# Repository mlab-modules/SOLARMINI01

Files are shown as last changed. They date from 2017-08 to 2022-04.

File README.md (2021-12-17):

[Czech](./README.cs.md)
<!--- module --->
# SOLARMINI01A
<!--- Emodule --->

<!--- subtitle ---> MPPT module for up to 5 Watt photovoltaic panel.<!--- Esubtitle --->

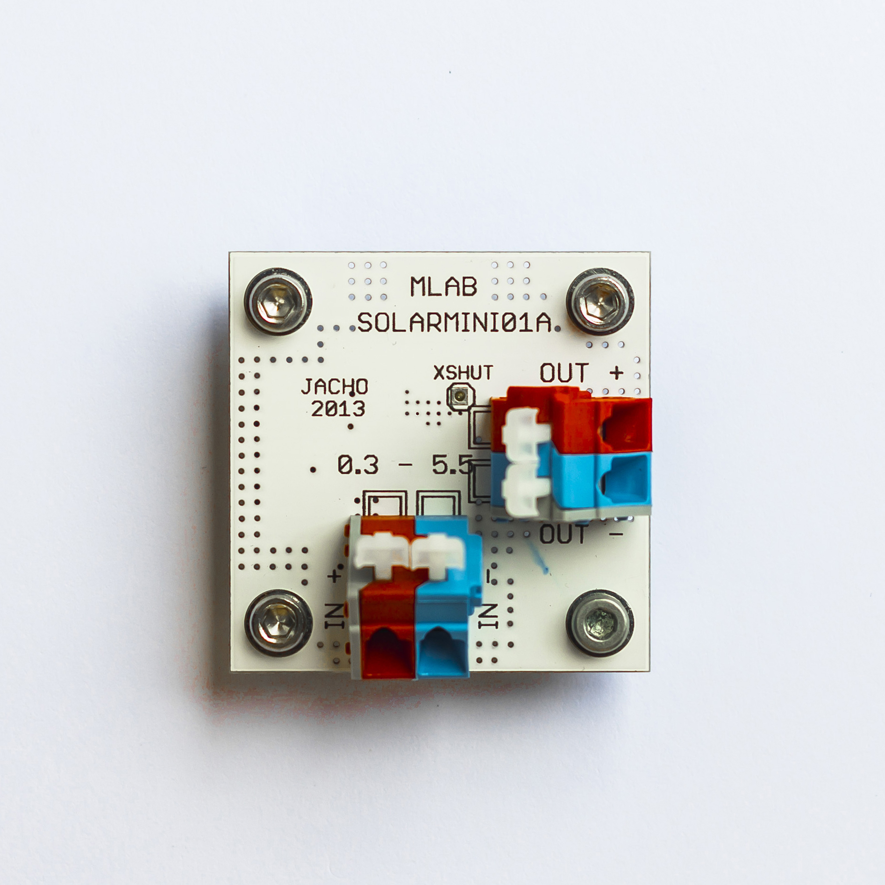
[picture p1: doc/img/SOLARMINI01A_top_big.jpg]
SOLARMINI01A


<!--- description ---> Module permanently search maximum power point of connected photovoltaic panel and convert the generated energy to higher voltages (5V maximum). It can be used for single cell or few serial connected cells. <!--- Edescription --->

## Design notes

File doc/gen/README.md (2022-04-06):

# PCB

Board size: 40.13x40.13 mm (1.58x1.58 inches)

- This is the size of the rectangle that contains the board
- Thickness: 1.6 mm (63 mils)
- Material: FR4
- Finish: None
- Layers: 2
- Copper thickness: 35 µm

Solder mask: TOP / BOTTOM

- Color: Green

Silk screen: TOP / BOTTOM

- Color: White

Stackup:

| Name | Type | Color | Thickness | Material | Epsilon_r | Loss tangent |
|---|---|---|---|---|---|---|
| F.SilkS | Top Silk Screen | | | | | |
| F.Paste | Top Solder Paste | | | | | |
| F.Mask | Top Solder Mask | Green | 10 | | | |
| F.Cu | copper | | 35 | | | |
| dielectric 1 | core | | 1510 | FR4 | 4.5 | 0.02 |
| B.Cu | copper | | 35 | | | |
| B.Mask | Bottom Solder Mask | Green | 10 | | | |
| B.Paste | Bottom Solder Paste  | | | | | |
| B.SilkS | Bottom Silk Screen | | | | | |

# Important sizes

Clearance: 0.2 mm (8 mils)

Track width: 0.3 mm (12 mils)

- By design rules: 0.2 mm (8 mils)

Drill: 0.4 mm (16 mils)

- Vias: 0.4 mm (16 mils) [Design: 0.3 mm (12 mils)]
- Pads: 0.89 mm (35 mils)

Via: 0.8/0.4 mm (31/16 mils)

- By design rules: 0.4/0.3 mm (16/12 mils)
- Micro via: no [0.2/0.1 mm (8/4 mils)]
- Burried/blind via: no

Outer Annular Ring: 0.4 mm (16 mils)

- By design rules: 0.4 mm (16 mils)

Eurocircuits class: 4C

# General stats

Components count: (SMD/THT)

- Top: 0/8 (THT)
- Bottom: 19/1 (SMD + THT)

Defined tracks:

- 0.2 mm (8 mils)
- 0.3 mm (12 mils)
- 0.4 mm (16 mils)
- 0.5 mm (20 mils)
- 0.6 mm (24 mils)
- 0.7 mm (28 mils)
- 1.0 mm (39 mils)

Used tracks:

- 0.3 mm (12 mils) (18) defined: yes
- 0.5 mm (20 mils) (29) defined: yes

Defined vias:

- 0.8/0.4 mm (31/16 mils)

Used vias:

- 0.8/0.4 mm (31/16 mils) (Count: 67, Aspect: 2.0 A) defined: yes

Holes (excluding vias):

- 0.89 mm (35 mils) (7)
- 1.3 mm (51 mils) (4)
- 3.0 mm (118 mils) (4)

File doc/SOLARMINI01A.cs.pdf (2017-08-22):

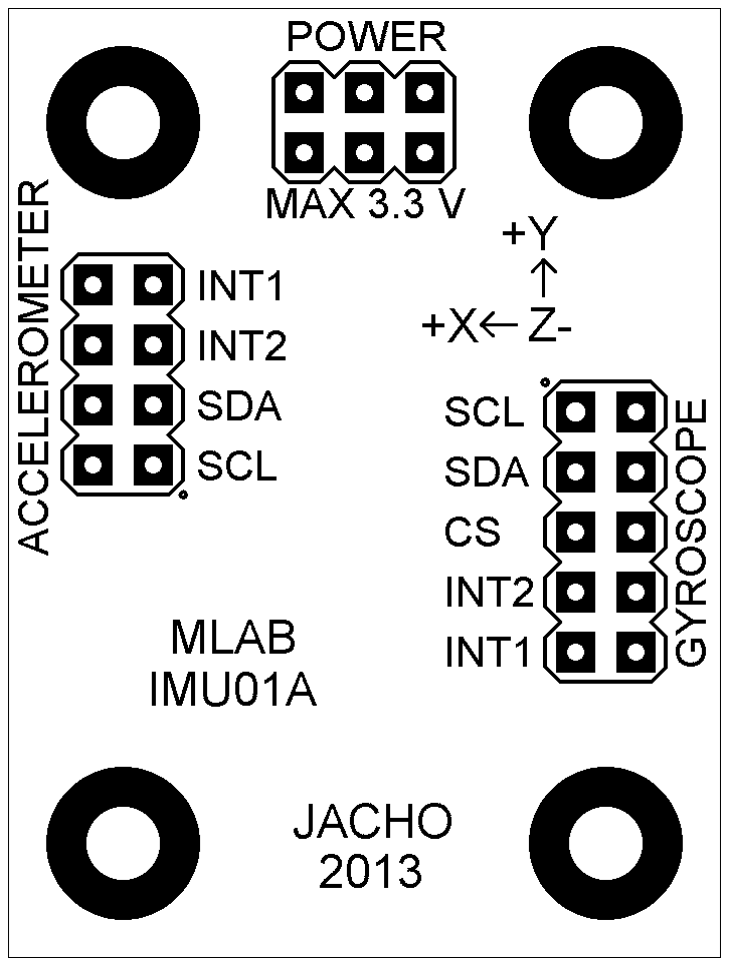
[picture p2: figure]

SOLARMINI01A / 2016-03-09 / jacho / http://www.mlab.cz | 1 / 3
SOLARMINI01A | MLAB

# DC/DC měnič pro solární články

Jan Chroust

# 1. Technické parametry

Parametr | Hodnota | Poznámka

Napájení

Integrovaný obvod

Využití

Rozhraní

Rozměry | 40.13 x 40.13 x 16 mm | Výška nad základní deskou

SOLARMINI01A | MLAB

# 2. Popis konstrukce

## 2.1. Úvod

## 2.2. Zapojení

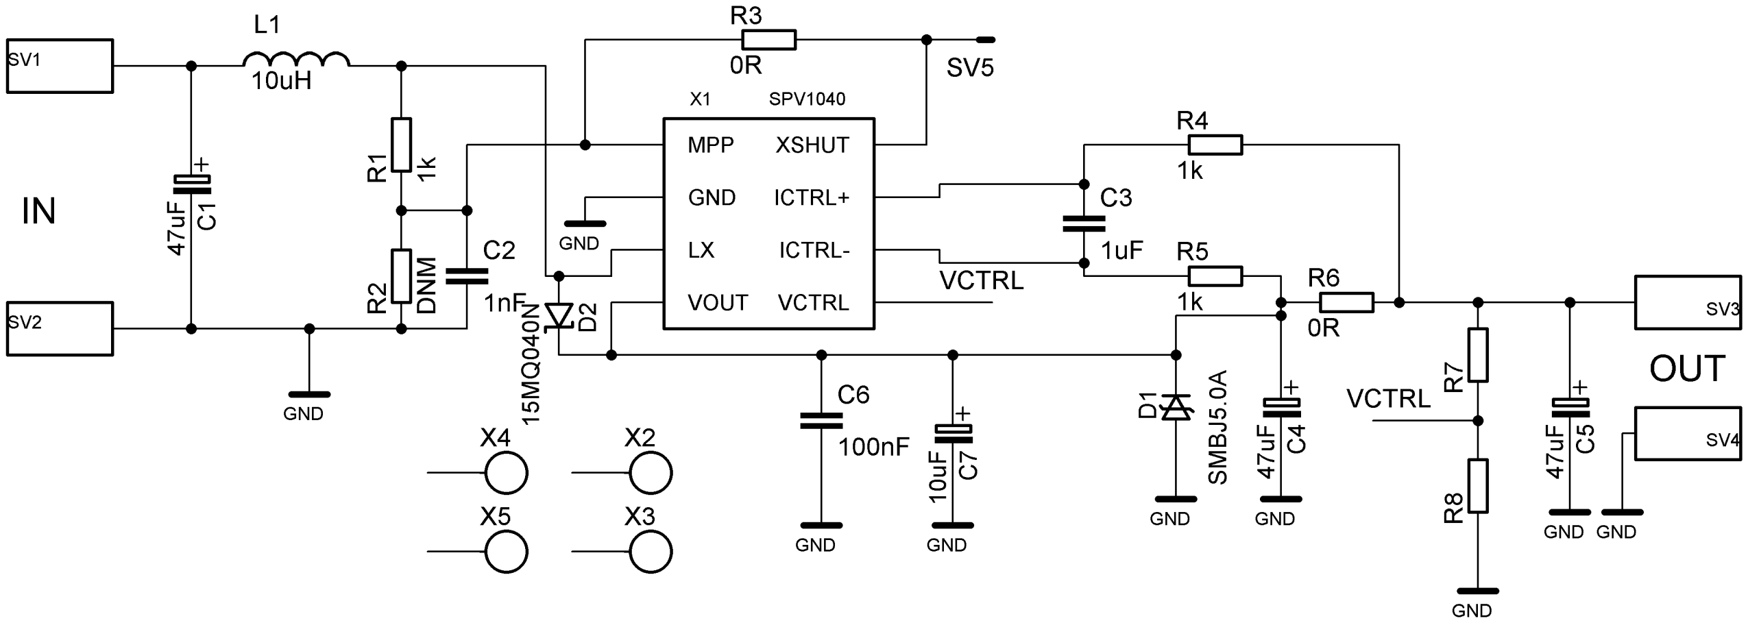
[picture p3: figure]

# 3. Osazení a oživení

SOLARMINI01A | MLAB

## 3.1. Osazení

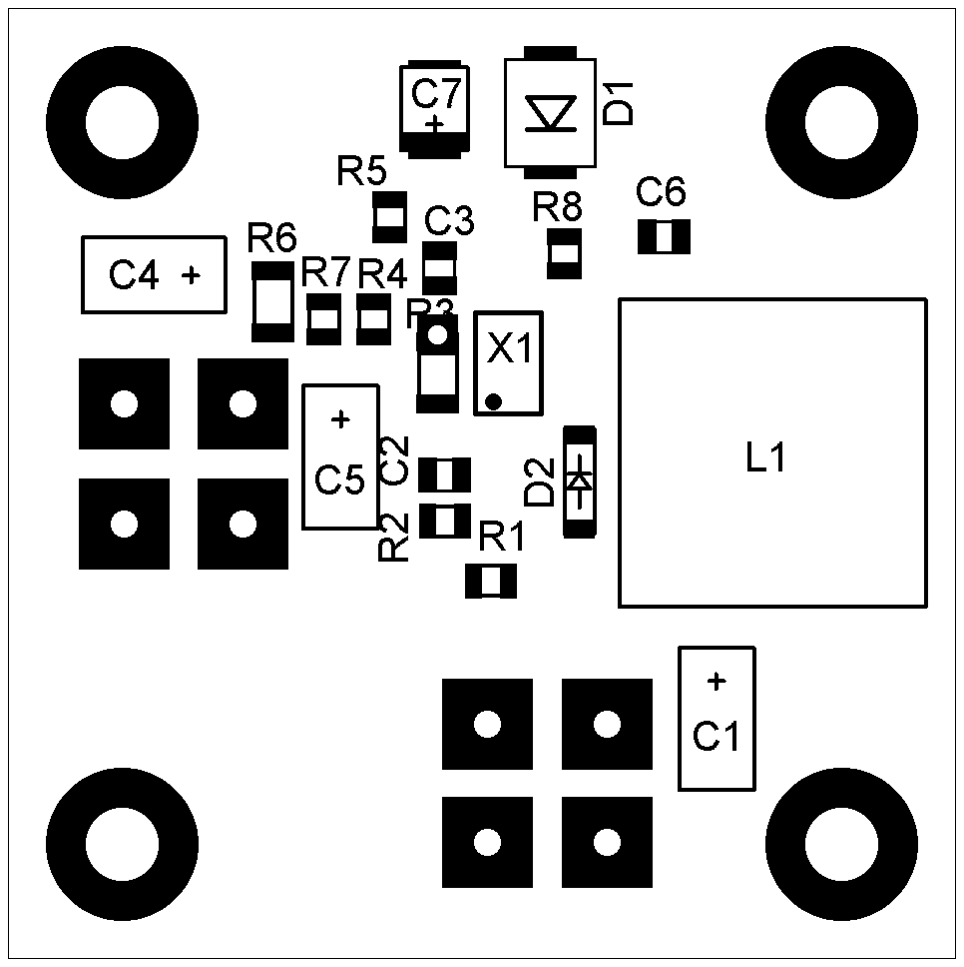
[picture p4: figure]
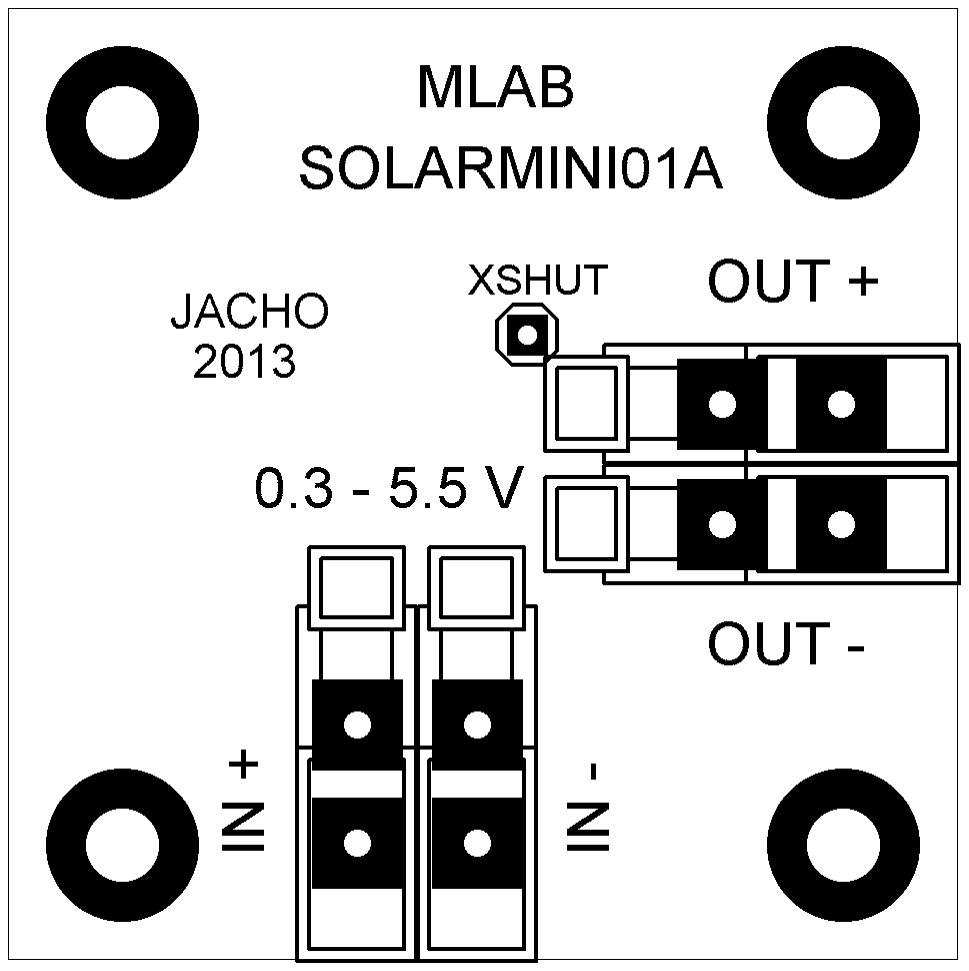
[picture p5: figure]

Označení | Typ (pouzdro) | Označení | Typ (pouzdro)
C1,C4, C5 | 47uF ( C ) | R1, R4, R5 | 1k (0805)
C2 | 1nF (0805) | R2 | DNM (0805)
C3 | 1uF (0805) | R3, R6 | 0R (1206)
C6 | 100nF (0805) | R7 | X (0805)
C7 | 10uF (B) | R8 | X(0805)
D1 | SMBJ5.0A (SMA) | SV1 - SV4 | WAGO256
D2 | 15MQ040N (SMA) | X1 | SPV1040
L1 | DE1205-10 | X2 - X5 | Šroub M3

## 3.2. Oživení

Po osazení modulu je dobré provést vizuální kontrolu, případně proměřit, zda na napájení není zkrat. Další oživení není potřeba.

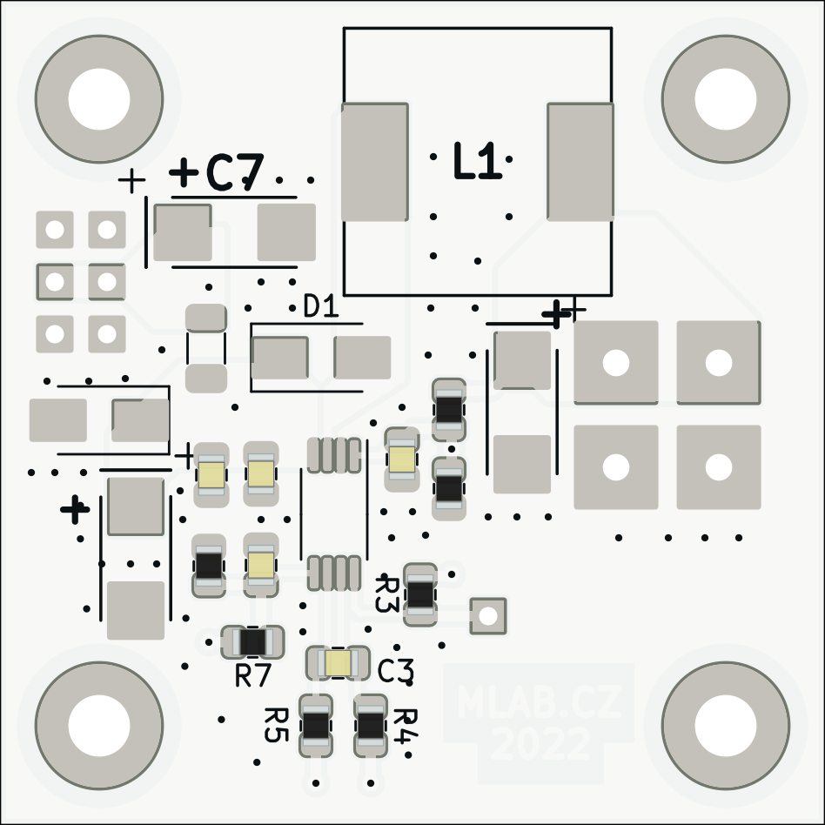
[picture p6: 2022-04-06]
doc/gen/img/SOLARMINI01B-bottom.png

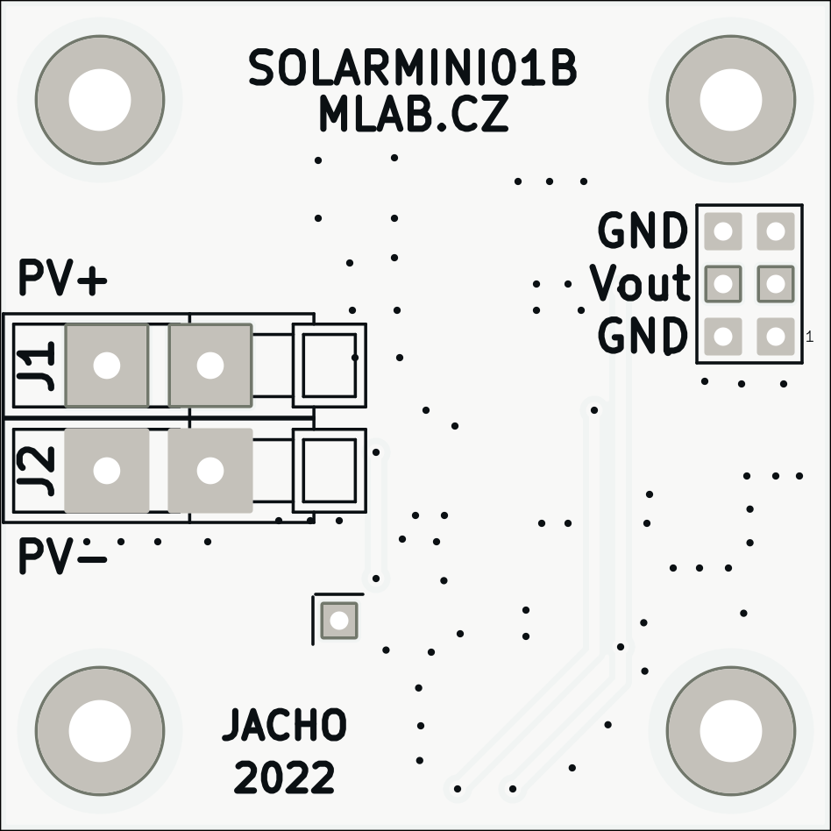
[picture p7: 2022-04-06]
doc/gen/img/SOLARMINI01B-top.png

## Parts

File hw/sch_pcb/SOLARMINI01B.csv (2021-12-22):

Source: | F:\MLAB_G\Moduly_zvlast\SOLARMINI01\hw\sch_pcb\SOLARMINI01B.kicad_sch
Date: | 22.12.2021 12:41:42
Tool: | Eeschema (5.99.0-13046-g4fe9f01eb0)
Generator: | C:\Program Files\KiCad\5.99\bin\scripting\plugins/bom_csv_grouped_by_value.py
Component Count: | 28
Individual Components:
Item | Qty | Reference(s) | Value | LibPart | Footprint | Datasheet | UST_ID
 |  | C1 | 47uF/16 | Device:C_Polarized | Mlab_C:TantalC_SizeC_Reflow | ~ | 5c70984412875079b91f8867
 |  | C2 | 100nF | Device:C | Capacitor_SMD:C_0805_2012Metric | ~ | 5c70984712875079b91f8b4c
 |  | C3 | 1uF | Device:C | Capacitor_SMD:C_0805_2012Metric | ~ | 5c70984712875079b91f8b50
 |  | C4 | 100nF | Device:C | Capacitor_SMD:C_0805_2012Metric | ~ | 5c70984712875079b91f8b4c
 |  | C5 | 10uF | Device:C | Capacitor_SMD:C_0805_2012Metric | ~ | 5c70984812875079b91f8bbd
 |  | C6 | 47uF/16 | Device:C_Polarized | Mlab_C:TantalC_SizeC_Reflow | ~ | 5c70984412875079b91f8867
 |  | C7 | 47uF/16 | Device:C_Polarized | Mlab_C:TantalC_SizeC_Reflow | ~ | 5c70984412875079b91f8867
 |  | C8 | 1nF | Device:C | Capacitor_SMD:C_0805_2012Metric | ~ | 5c70984712875079b91f8b45
 |  | D1 | 15MQ040N | Device:D_Schottky | Diode_SMD:D_SMA | ~ | 5c70984512875079b91f88b0
 |  | D2 | SMBJ5.0A | Device:D_Zener | Diode_SMD:D_SMA | ~ | 5c70984512875079b91f88c7
 |  | J1 | WAGO 256 RED | MLAB_Jumpers:CONN1_1 | Mlab_CON:WAGO256 |  | 5c70984412875079b91f87c5
 |  | J2 | WAGO 256 BLUE | MLAB_Jumpers:CONN1_1 | Mlab_CON:WAGO256 |  | 5c70984412875079b91f87c3
 |  | J3 | HEADER_1x01 | MLAB_HEADER:HEADER_1x01 | Mlab_Pin_Headers:Straight_1x01
 |  | J4 | HEADER_2x03_PARALLEL | MLAB_HEADER:HEADER_2x03_PARALLEL | Mlab_Pin_Headers:Straight_2x03
 |  | L1 | 10uH - DE1205-10 | Device:L_Small | Mlab_L:DE1205-10 | ~ | 5c70984412875079b91f8822
 |  | M1 | HOLE | MLAB_MECHANICAL:HOLE | Mlab_Mechanical:MountingHole_3mm
 |  | M2 | HOLE | MLAB_MECHANICAL:HOLE | Mlab_Mechanical:MountingHole_3mm
 |  | M3 | HOLE | MLAB_MECHANICAL:HOLE | Mlab_Mechanical:MountingHole_3mm
 |  | M4 | HOLE | MLAB_MECHANICAL:HOLE | Mlab_Mechanical:MountingHole_3mm
 |  | R1 | 1k | Device:R | Resistor_SMD:R_0805_2012Metric | ~ | 5c70984512875079b91f898c
 |  | R2 | - | Device:R | Resistor_SMD:R_0805_2012Metric | ~
 |  | R3 | 0R | Device:R | Resistor_SMD:R_0805_2012Metric | ~ | 5c70984512875079b91f896b
 |  | R4 | 1k | Device:R | Resistor_SMD:R_0805_2012Metric | ~ | 5c70984512875079b91f898c
 |  | R5 | 1k | Device:R | Resistor_SMD:R_0805_2012Metric | ~ | 5c70984512875079b91f898c
 |  | R6 | 0R47 | Device:R | Resistor_SMD:R_1206_3216Metric | ~ | 60be2ed51287500165e6c1cd
 |  | R7 | 560k | Device:R | Resistor_SMD:R_0805_2012Metric | ~ | 5c70984712875079b91f8aa6
 |  | R8 | 270k | Device:R | Resistor_SMD:R_0805_2012Metric | ~ | 5c70984712875079b91f8aa0
 |  | U1 | SPV1040 | MLAB_IO:SPV1040 | Package_SO:TSSOP-8_4.4x3mm_P0.65mm |  | 5c70984612875079b91f89bc
Collated Components:
Item | Qty | Reference(s) | Value | LibPart | Footprint | Datasheet | UST_ID
1 | 3 | C1, C6, C7 | 47uF/16 | Device:C_Polarized | Mlab_C:TantalC_SizeC_Reflow | ~ | 5c70984412875079b91f8867
2 | 2 | C2, C4 | 100nF | Device:C | Capacitor_SMD:C_0805_2012Metric | ~ | 5c70984712875079b91f8b4c
3 | 1 | C3 | 1uF | Device:C | Capacitor_SMD:C_0805_2012Metric | ~ | 5c70984712875079b91f8b50
4 | 1 | C5 | 10uF | Device:C | Capacitor_SMD:C_0805_2012Metric | ~ | 5c70984812875079b91f8bbd
5 | 1 | C8 | 1nF | Device:C | Capacitor_SMD:C_0805_2012Metric | ~ | 5c70984712875079b91f8b45
6 | 1 | D1 | 15MQ040N | Device:D_Schottky | Diode_SMD:D_SMA | ~ | 5c70984512875079b91f88b0
7 | 1 | D2 | SMBJ5.0A | Device:D_Zener | Diode_SMD:D_SMA | ~ | 5c70984512875079b91f88c7
8 | 1 | J1 | WAGO 256 RED | MLAB_Jumpers:CONN1_1 | Mlab_CON:WAGO256 |  | 5c70984412875079b91f87c5
9 | 1 | J2 | WAGO 256 BLUE | MLAB_Jumpers:CONN1_1 | Mlab_CON:WAGO256 |  | 5c70984412875079b91f87c3
10 | 1 | J3 | HEADER_1x01 | MLAB_HEADER:HEADER_1x01 | Mlab_Pin_Headers:Straight_1x01
11 | 1 | J4 | HEADER_2x03_PARALLEL | MLAB_HEADER:HEADER_2x03_PARALLEL | Mlab_Pin_Headers:Straight_2x03
12 | 1 | L1 | 10uH - DE1205-10 | Device:L_Small | Mlab_L:DE1205-10 | ~ | 5c70984412875079b91f8822
13 | 4 | M1, M2, M3, M4 | HOLE | MLAB_MECHANICAL:HOLE | Mlab_Mechanical:MountingHole_3mm
14 | 3 | R1, R4, R5 | 1k | Device:R | Resistor_SMD:R_0805_2012Metric | ~ | 5c70984512875079b91f898c
15 | 1 | R2 | - | Device:R | Resistor_SMD:R_0805_2012Metric | ~
16 | 1 | R3 | 0R | Device:R | Resistor_SMD:R_0805_2012Metric | ~ | 5c70984512875079b91f896b
17 | 1 | R6 | 0R47 | Device:R | Resistor_SMD:R_1206_3216Metric | ~ | 60be2ed51287500165e6c1cd
18 | 1 | R7 | 560k | Device:R | Resistor_SMD:R_0805_2012Metric | ~ | 5c70984712875079b91f8aa6
19 | 1 | R8 | 270k | Device:R | Resistor_SMD:R_0805_2012Metric | ~ | 5c70984712875079b91f8aa0
20 | 1 | U1 | SPV1040 | MLAB_IO:SPV1040 | Package_SO:TSSOP-8_4.4x3mm_P0.65mm |  | 5c70984612875079b91f89bc

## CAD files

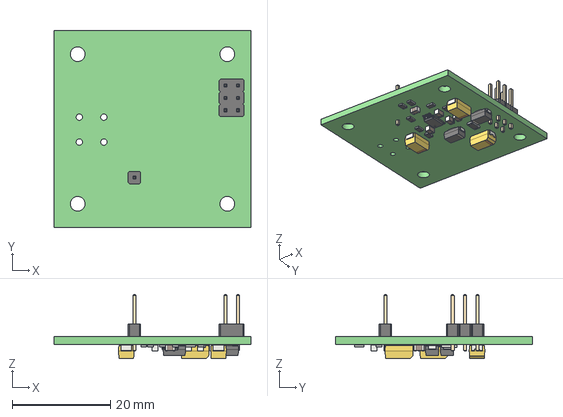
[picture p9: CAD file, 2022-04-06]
doc/gen/SOLARMINI01B.step
40.1 x 40.1 x 13.0 mm
tmp5e7hpwy7 PCB

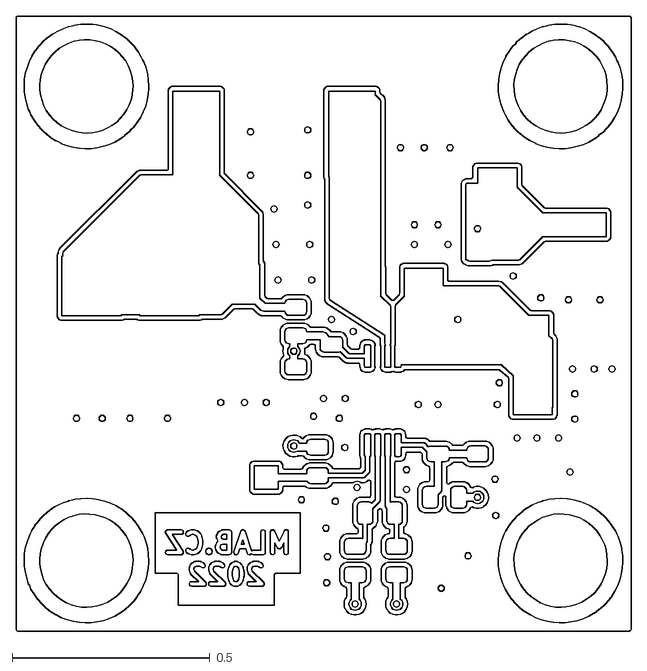
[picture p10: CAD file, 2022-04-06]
doc/gen/dxf/SOLARMINI01B-B_Cu.dxf
1.56 x 1.56

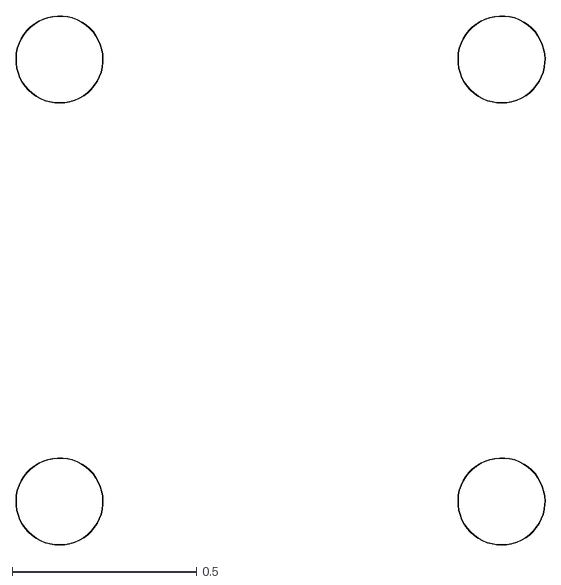
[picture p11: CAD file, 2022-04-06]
doc/gen/dxf/SOLARMINI01B-B_Adhesive.dxf
1.44 x 1.44

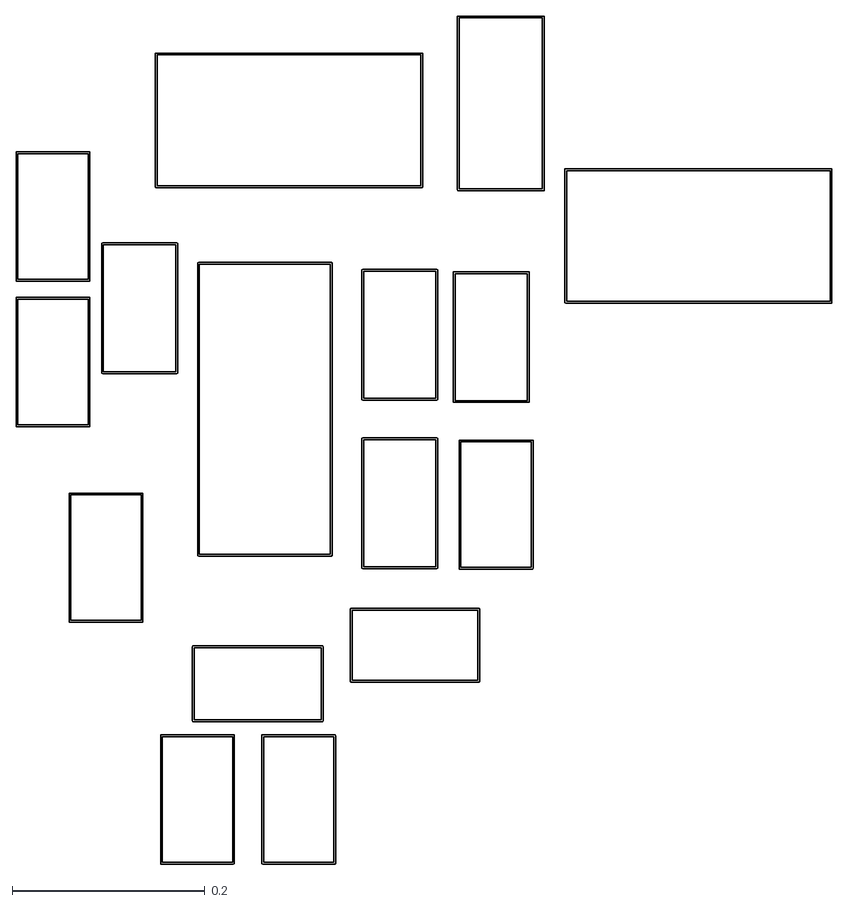
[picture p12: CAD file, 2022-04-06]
doc/gen/dxf/SOLARMINI01B-B_Courtyard.dxf
0.847 x 0.88

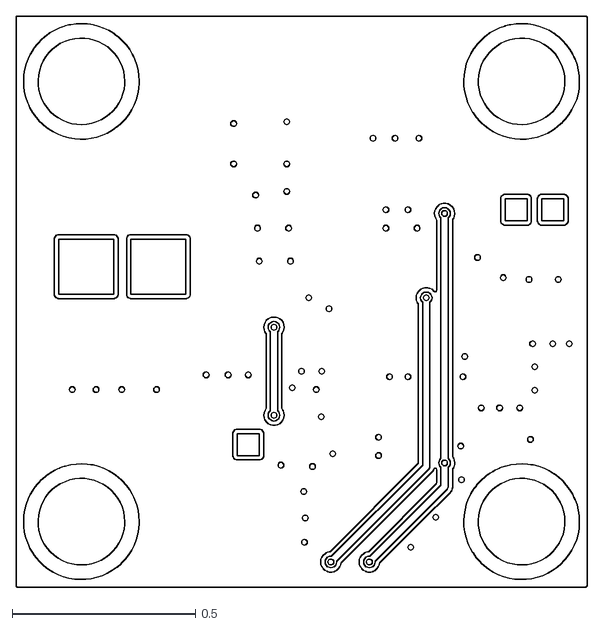
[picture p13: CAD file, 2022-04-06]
doc/gen/dxf/SOLARMINI01B-F_Cu.dxf
1.56 x 1.56

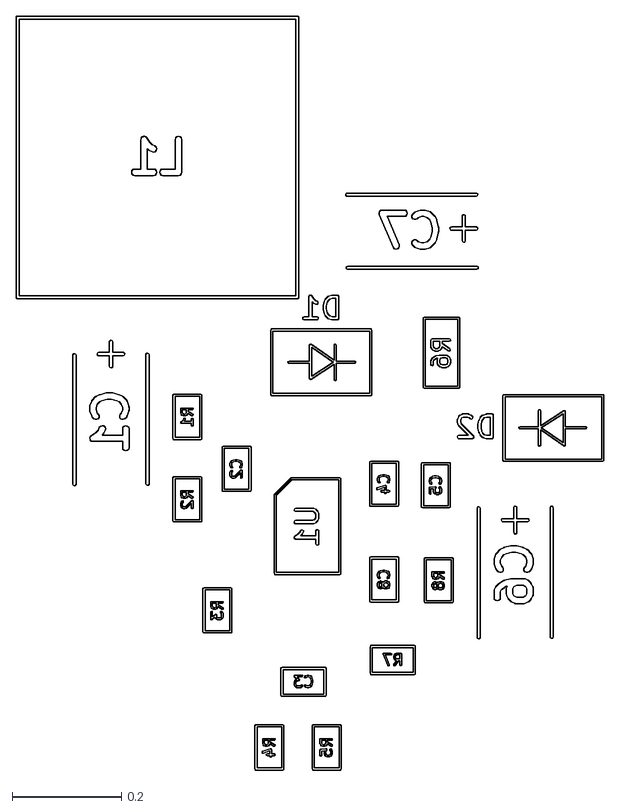
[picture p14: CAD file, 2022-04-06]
doc/gen/dxf/SOLARMINI01B-B_Fab.dxf
1.08 x 1.38

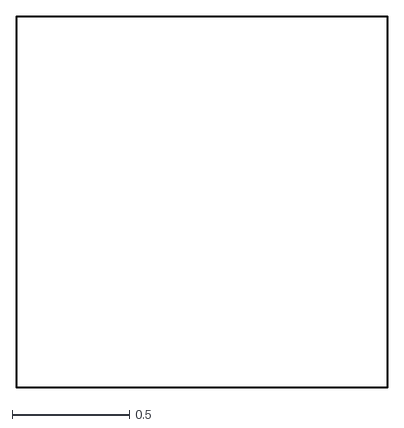
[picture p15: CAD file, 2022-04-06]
doc/gen/dxf/SOLARMINI01B-Edge_Cuts.dxf
1.58 x 1.58

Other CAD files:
doc/gen/dxf/SOLARMINI01B-F_Courtyard.dxf
doc/gen/dxf/SOLARMINI01B-User_1.dxf
doc/gen/dxf/SOLARMINI01B-User_8.dxf
doc/gen/dxf/SOLARMINI01B-User_9.dxf
doc/gen/dxf/SOLARMINI01B-User_Drawings.dxf
doc/gen/dxf/SOLARMINI01B-User_4.dxf
doc/gen/dxf/SOLARMINI01B-Margin.dxf
doc/gen/dxf/SOLARMINI01B-User_5.dxf
doc/gen/dxf/SOLARMINI01B-User_3.dxf
doc/gen/dxf/SOLARMINI01B-User_2.dxf
doc/gen/dxf/SOLARMINI01B-B_Mask.dxf
doc/gen/dxf/SOLARMINI01B-B_Paste.dxf
doc/gen/dxf/SOLARMINI01B-B_Silkscreen.dxf
doc/gen/dxf/SOLARMINI01B-F_Fab.dxf
doc/gen/dxf/SOLARMINI01B-F_Mask.dxf
doc/gen/dxf/SOLARMINI01B-F_Paste.dxf
doc/gen/dxf/SOLARMINI01B-F_Silkscreen.dxf
doc/gen/dxf/SOLARMINI01B-User_6.dxf
doc/gen/dxf/SOLARMINI01B-User_7.dxf
doc/gen/dxf/SOLARMINI01B-User_Comments.dxf
doc/gen/dxf/SOLARMINI01B-User_Eco1.dxf
doc/gen/dxf/SOLARMINI01B-User_Eco2.dxf

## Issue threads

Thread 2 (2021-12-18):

Alternative ICs for updated module

kaklik, 2021-12-18:
- [MP2731](https://www.monolithicpower.com/en/battery-charger-with-mppt) - zřejmě vhodné pro větší vícečlánkové akumulátory a vícečlánkové fotovoltaické panely
- [SPV1050 Ultra low power energy harvester and battery charger](https://www.st.com/en/power-management/spv1050.html) - Maximální výstupní proud zřejmě je pouze 70mA.
- [AEM1094](https://e-peas.com/wp-content/uploads/2021/03/e-peas-AEM10941-datasheet-energy-harvesting.pdf) - ze solárního panelu dovede odebrat proud pouze 110mA je tak vhodný na aplikace s nižšími výkonovými požadavky.

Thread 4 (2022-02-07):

Swapped ICTRL plus and minus pins

kaklik, 2022-02-07:
Figure 2. in the datasheet suggest the connection of ICTRL_PLUS on the source side of measuring resistor Rs and ICTRL_MINUS  ping should be connected to the sink/battery side of measuring resistor Rs.

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

Unfortunately, the current schematics have those pins swapped.

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

kaklik, 2022-02-07:
Solved in SOLARMINI01B revision

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

Closed 2022-02-07.

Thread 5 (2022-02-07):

Silkscreen

kaklik, 2022-02-07:
There is missing marking for XSHUT pin in the silksceen.

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

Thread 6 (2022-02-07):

ICTR signals routing

kaklik, 2022-02-07:
The ICTR+ and ICTR- are differential signals. Therefore, should be routed as the differential pair.  The current routing does not minimize induction noise to the current sensing loop.

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

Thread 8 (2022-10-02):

divider for LTO cells

kakl, 2022-10-02:
delic v solarmini je 100:110 k ohm
dava to 2,69 V az 2,77 V naprazdno pri 1 % odporech
R7 = 110 k
R8 = 100 k

kakl, 2022-10-02:
R7 = 100 k
R8 = 91 k
dava 2,76 V, to je jeste lepsi

kaklik, 2023-05-13:
Je to aplikováno v [návrhu nového modulu pro LTO články](https://github.com/mlab-modules/SOLARMINIBAT01).

Closed 2023-05-13.

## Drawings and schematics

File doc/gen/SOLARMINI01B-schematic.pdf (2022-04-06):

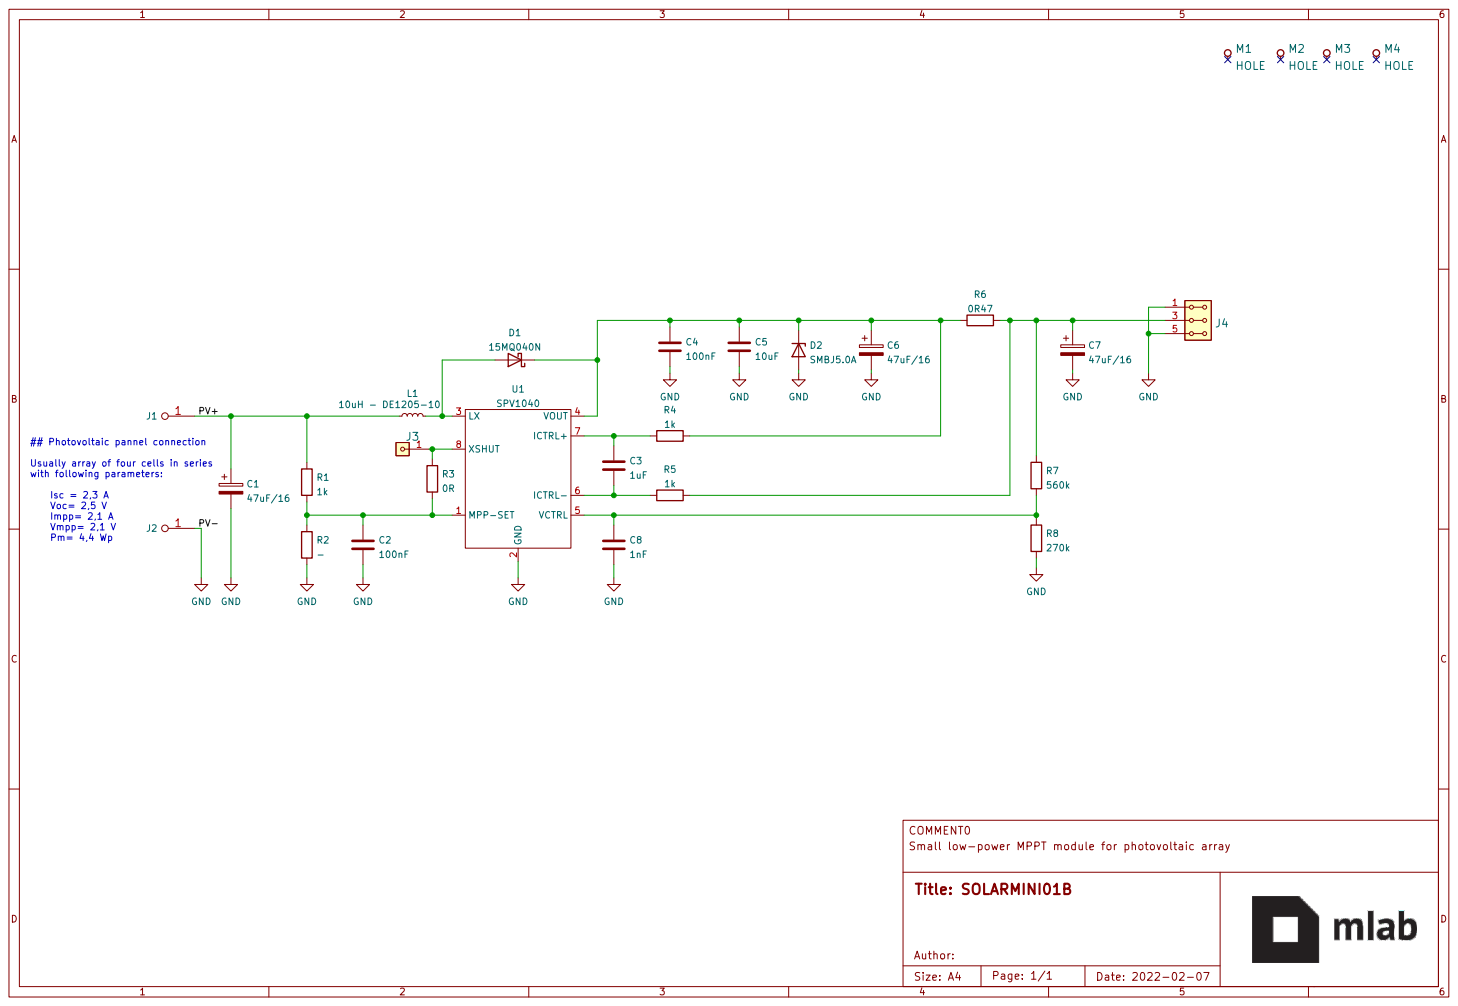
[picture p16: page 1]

Usually array of four cells in series
with following parameters:

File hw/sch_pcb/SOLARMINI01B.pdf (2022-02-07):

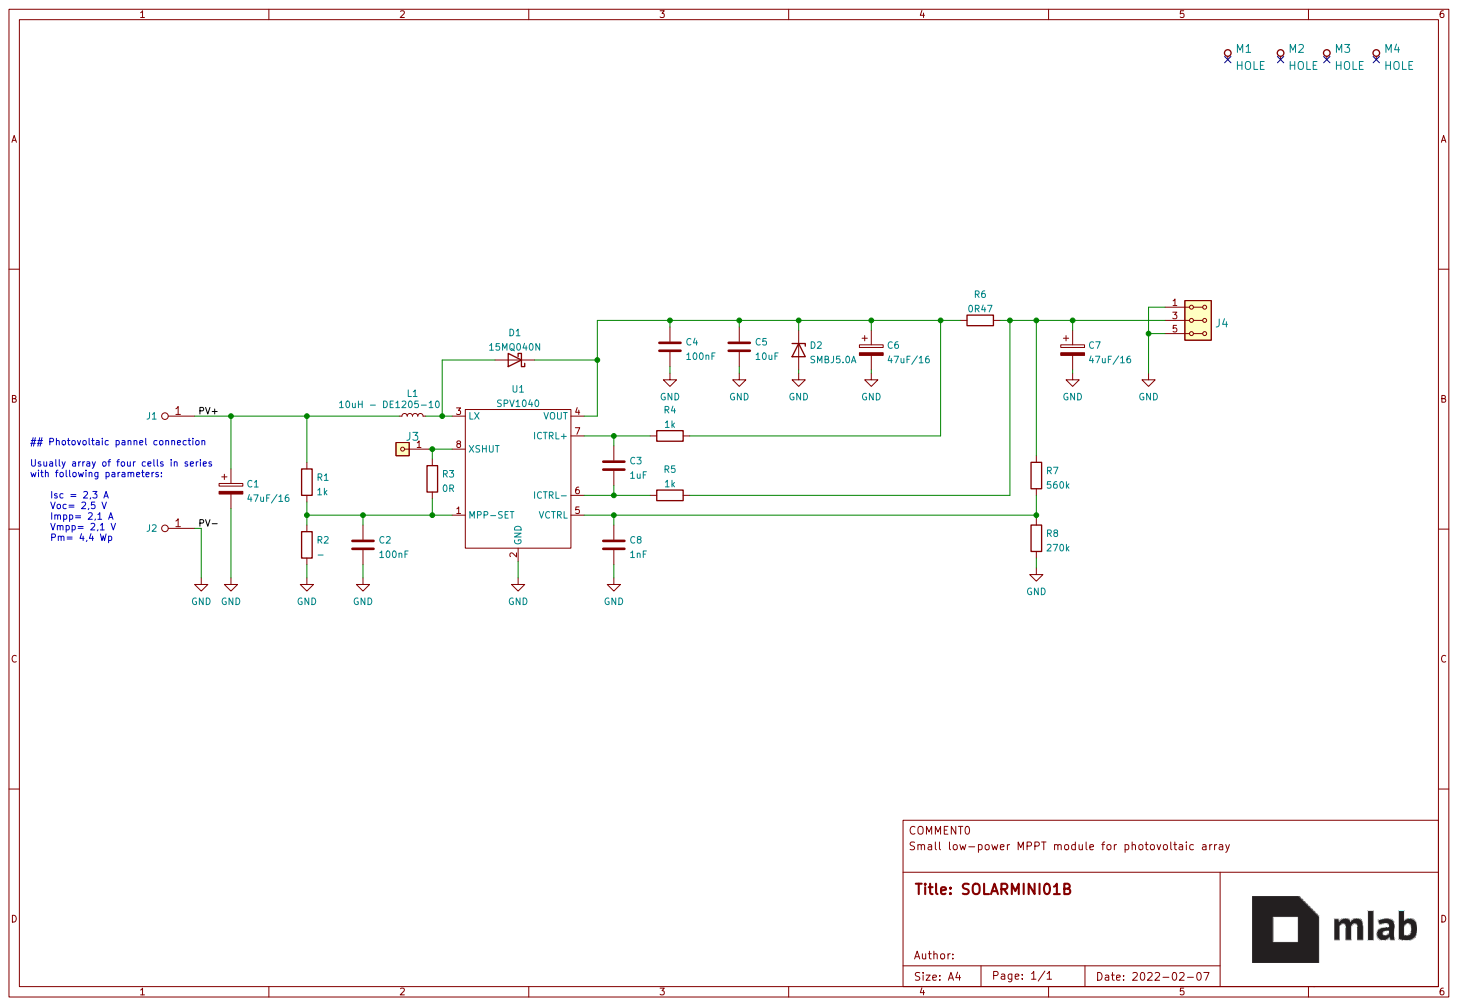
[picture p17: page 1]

Usually array of four cells in series
with following parameters:

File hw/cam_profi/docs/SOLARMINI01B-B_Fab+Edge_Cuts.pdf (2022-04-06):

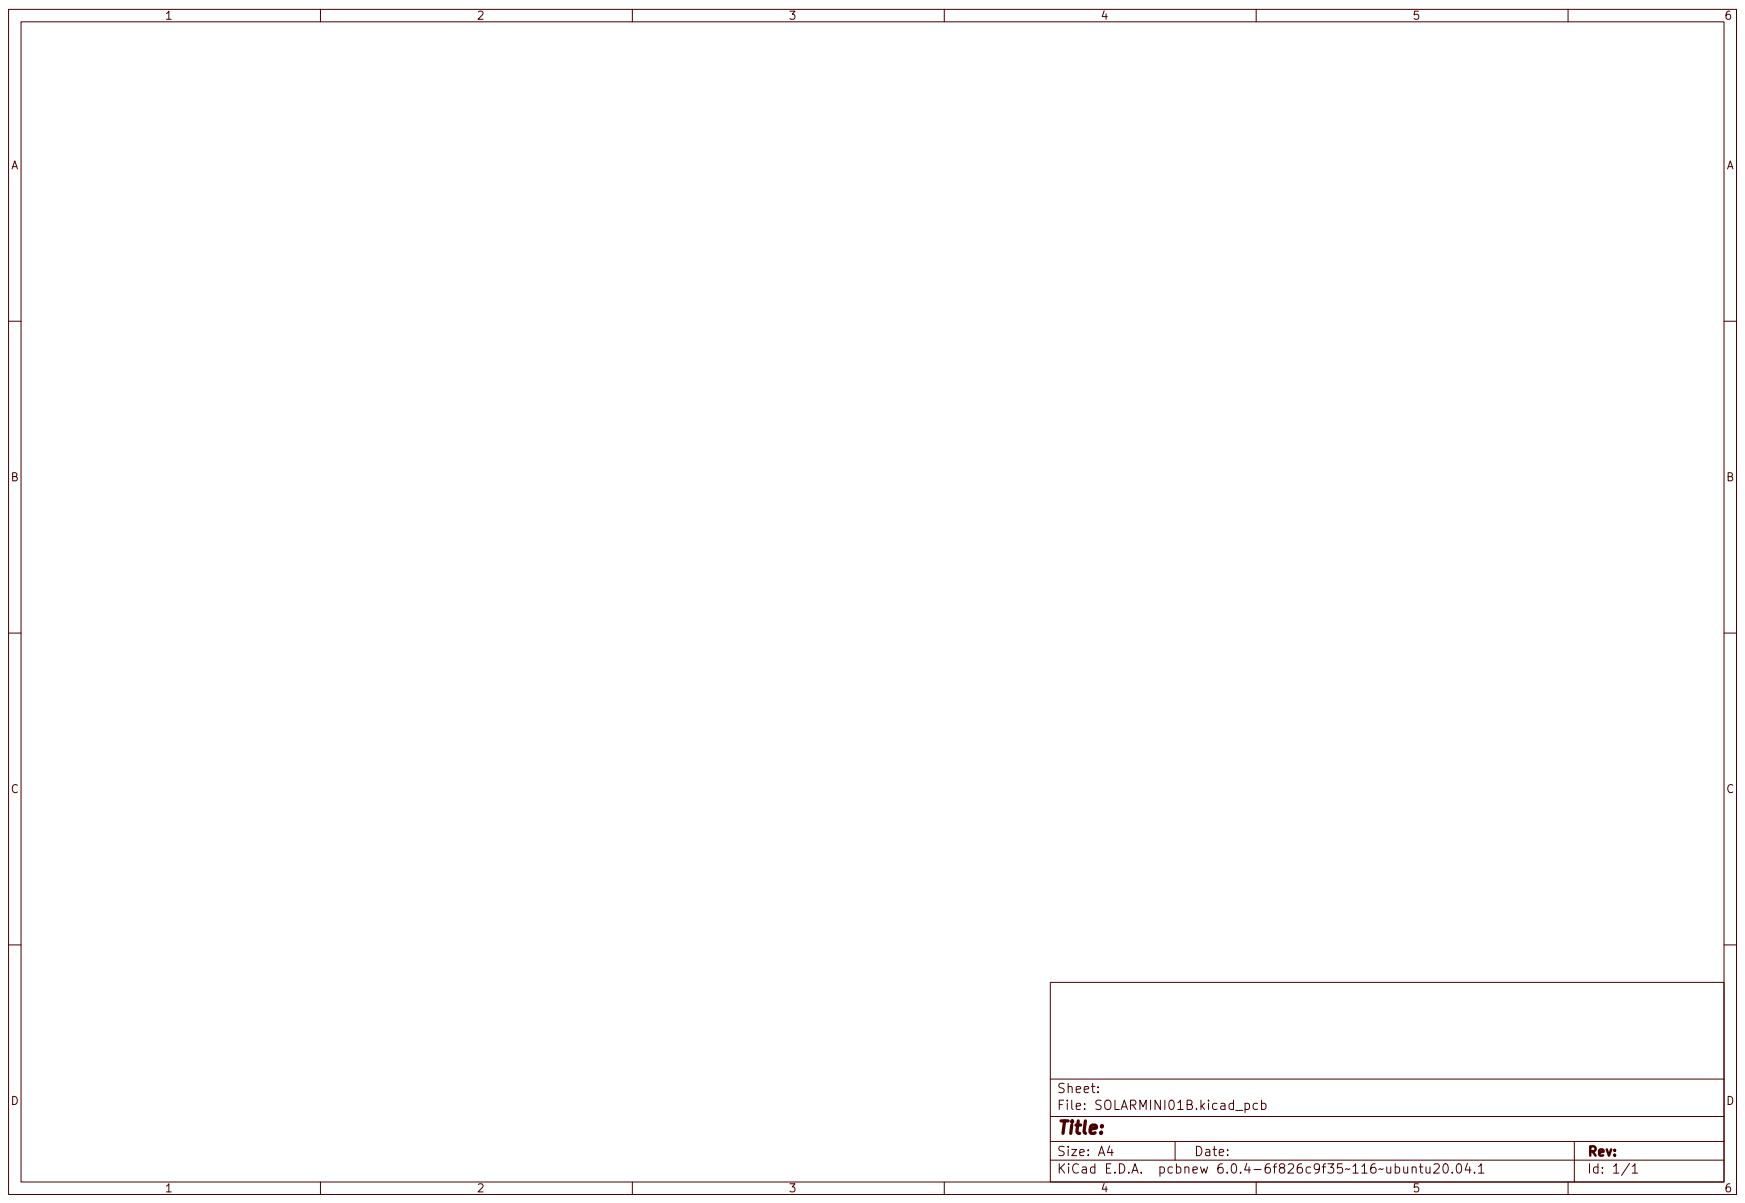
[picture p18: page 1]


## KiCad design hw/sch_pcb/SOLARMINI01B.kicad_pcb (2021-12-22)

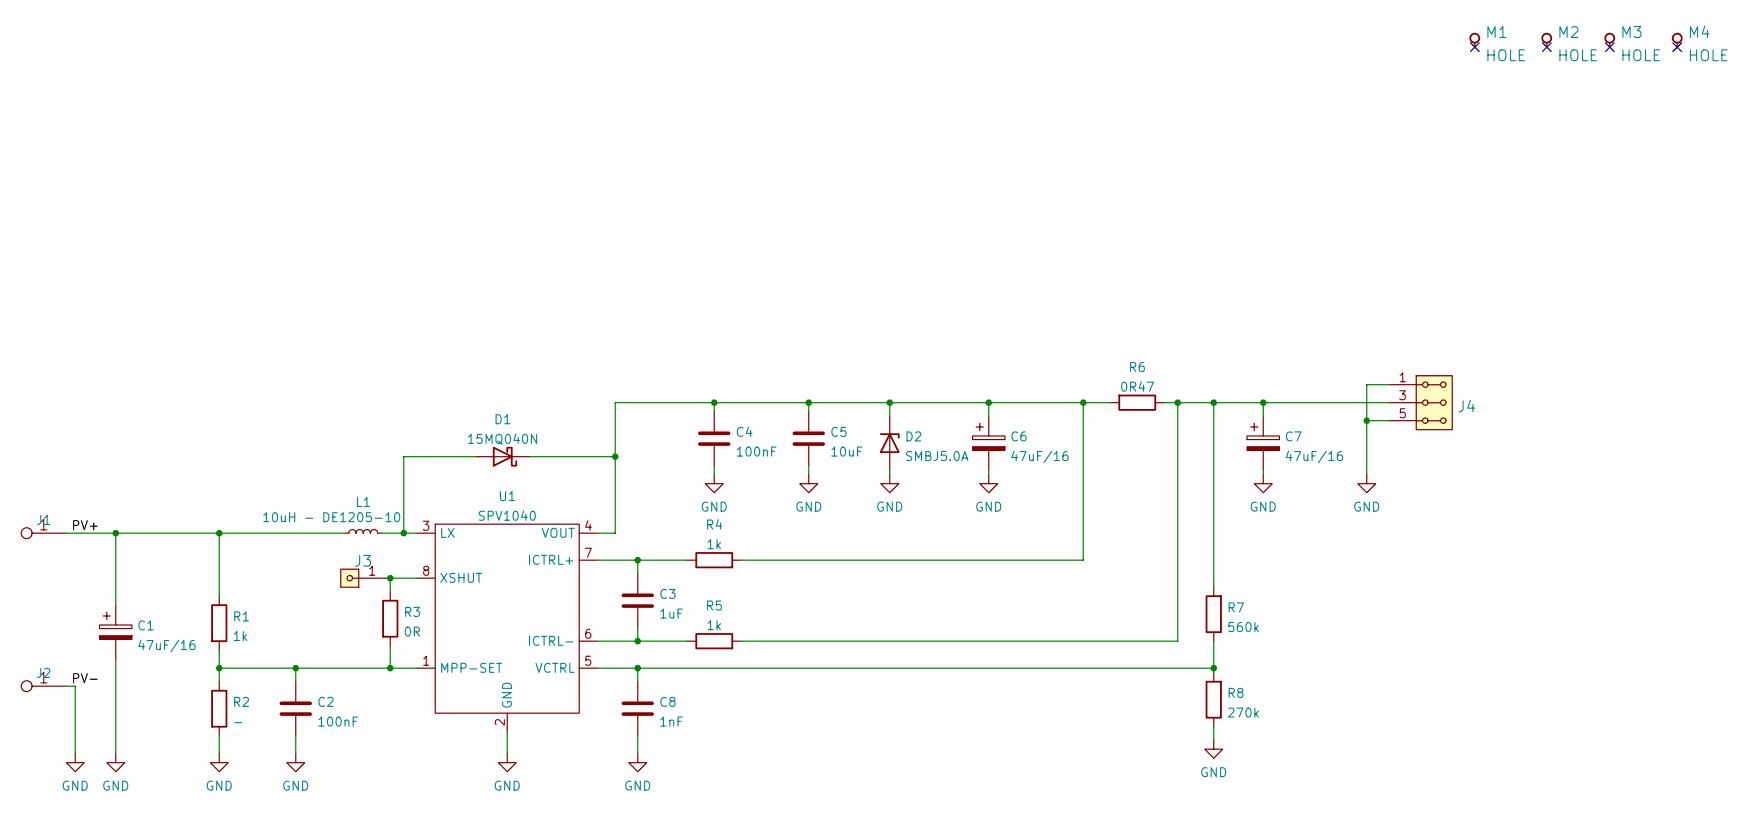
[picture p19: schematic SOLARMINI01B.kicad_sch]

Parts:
C1, C6, C7: 47uF/16; TantalC_SizeC_Reflow
C2, C4: 100nF; C_0805_2012Metric
C3: 1uF; C_0805_2012Metric
C5: 10uF; C_0805_2012Metric
C8: 1nF; C_0805_2012Metric
D1: 15MQ040N; D_SMA
D2: SMBJ5.0A; D_SMA
J1: WAGO 256 RED; WAGO256
J2: WAGO 256 BLUE; WAGO256
J3: HEADER_1x01; Straight_1x01
J4: HEADER_2x03_PARALLEL; Straight_2x03
L1: 10uH - DE1205-10; DE1205-10
M1, M2, M3, M4: HOLE; MountingHole_3mm
R1, R4, R5: 1k; R_0805_2012Metric
R2: -; R_0805_2012Metric
R3: 0R; R_0805_2012Metric
R6: 0R47; R_1206_3216Metric
R7: 560k; R_0805_2012Metric
R8: 270k; R_0805_2012Metric
U1: SPV1040; TSSOP-8_4.4x3mm_P0.65mm

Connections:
/PV+: C1.1, J1.1, L1.1, R1.1
GND: C1.2, C2.2, C4.2, C5.2, C6.2, C7.2, C8.2, D2.2 (A), J2.1, J4.1, J4.2, J4.5, J4.6, R2.2, R8.1, U1.2 (GND)
unnamed: C2.1, R1.2, R2.1, R3.2, U1.1 (MPP-SET)
unnamed: C3.1, R4.1, U1.7 (ICTRL+)
unnamed: C3.2, R5.1, U1.6 (ICTRL-)
unnamed: C4.1, C5.1, C6.1, D1.1 (K), D2.1 (K), R4.2, R6.2, U1.4 (VOUT)
unnamed: C7.1, J4.3, J4.4, R5.2, R6.1, R7.2
unnamed: C8.1, R7.1, R8.2, U1.5 (VCTRL)
unnamed: D1.2 (A), L1.2, U1.3 (LX)
unnamed: J3.1, R3.1, U1.8 (XSHUT)

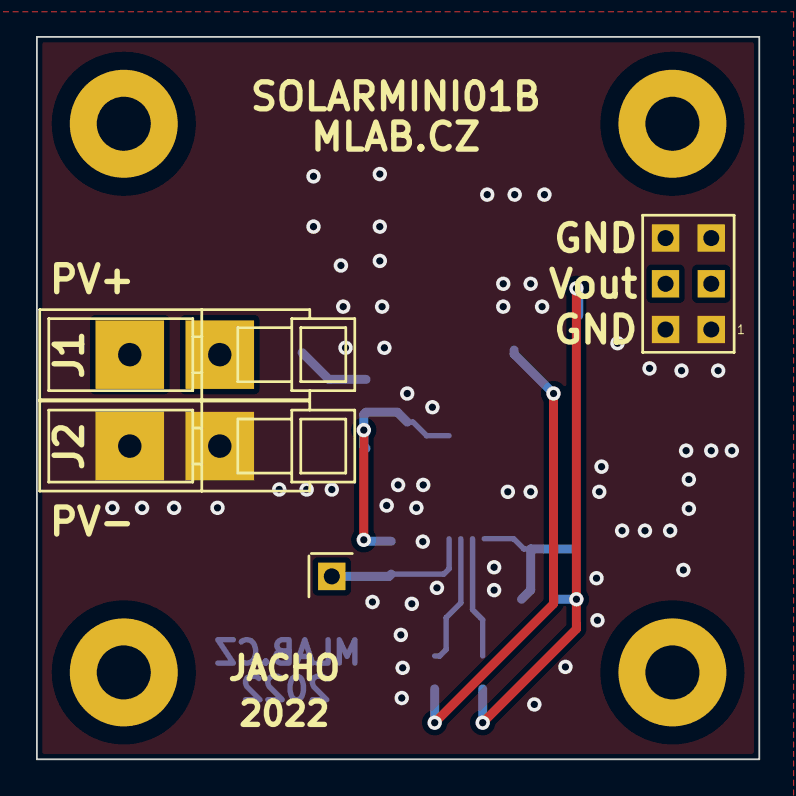
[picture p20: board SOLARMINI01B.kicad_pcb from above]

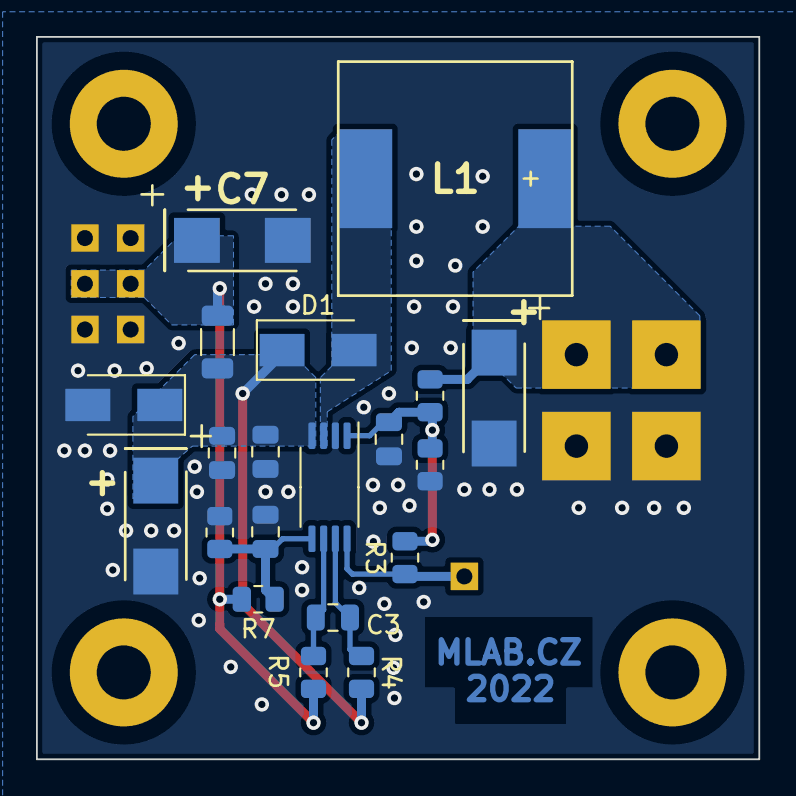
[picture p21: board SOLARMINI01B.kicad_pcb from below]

Board: 2 copper layers, 40.1 x 40.1 mm, 28 parts (20 on the bottom side), 10 nets.

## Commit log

2017-08-22 rename category folders
    [untitled.brd, untitled.sch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]
2017-08-22 rename files and module folders
    [untitled.brd, untitled.sch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]
2017-08-22 create hw folder
    [untitled.brd, untitled.sch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]
2021-12-20 Edit schema in KiCAD
    [SOLARMINI01B.kicad_pcb, SOLARMINI01B.kicad_sch, untitled.brd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]
2021-12-20 Edit strukture
    [SOLARMINI01B.kicad_pcb, SOLARMINI01B.kicad_sch]
2021-12-20 edit schema
    [SOLARMINI01B.kicad_sch]
2021-12-20 Edit PCB
    [SOLARMINI01B.kicad_pcb, SOLARMINI01B.kicad_sch]
2021-12-22 Úpravy PCB a generování výrobních dat.
    [SOLARMINI01B-B_Cu.gbr, SOLARMINI01B-B_Mask.gbr, SOLARMINI01B-Edge_Cuts.gbr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]
2021-12-22 Edit BOM
    [SOLARMINI01B.csv, SOLARMINI01B.kicad_pcb, SOLARMINI01B.kicad_sch]
2022-02-07 Update module documentation.
    [SOLARMINI01B.kicad_sch]
2022-04-06 Update actions products
    [SOLARMINI01B-B_Adhesive.dxf, SOLARMINI01B-B_Courtyard.dxf, SOLARMINI01B-B_Cu.dxf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]
